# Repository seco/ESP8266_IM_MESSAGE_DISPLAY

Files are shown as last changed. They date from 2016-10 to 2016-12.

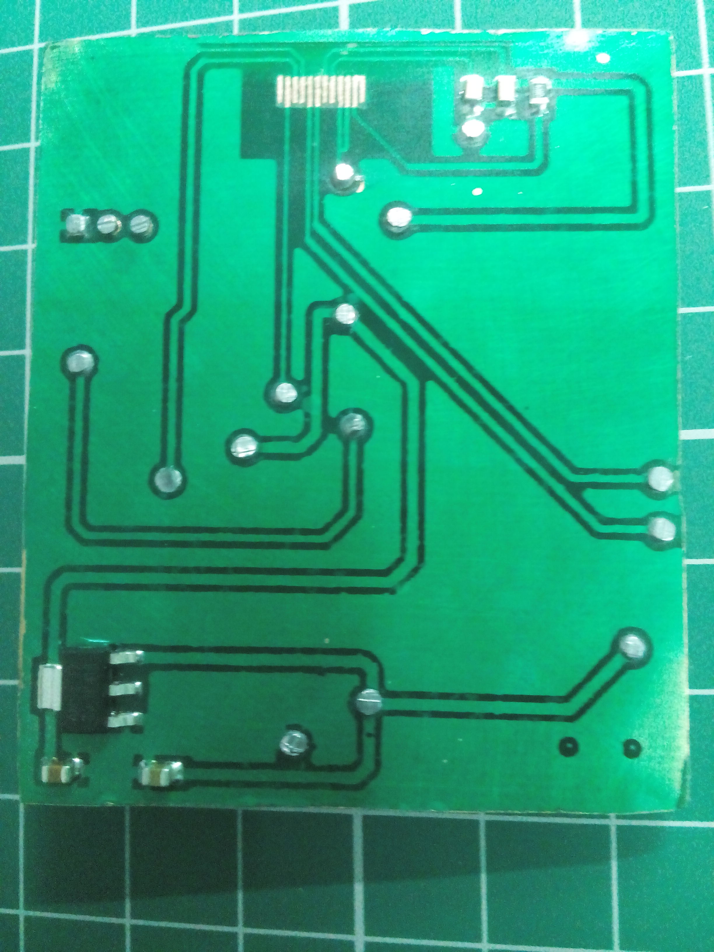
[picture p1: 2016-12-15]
pics/IMG_20161213_000737.jpg

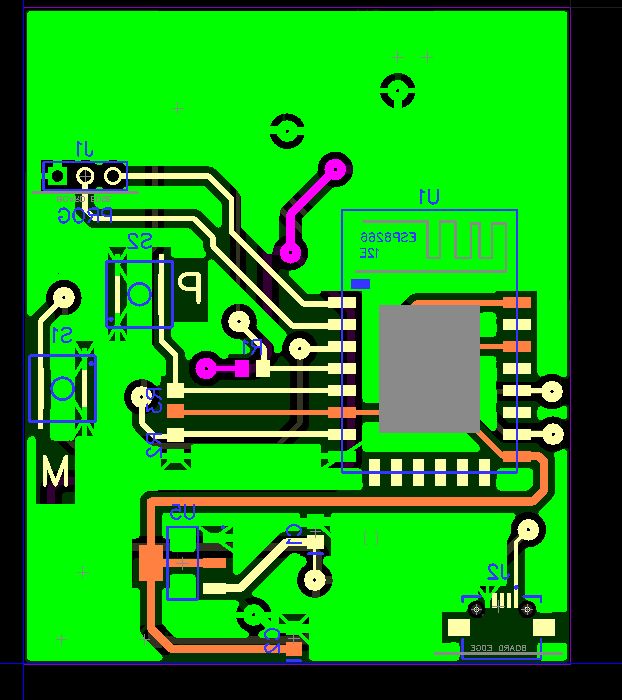
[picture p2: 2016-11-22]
pics/pcb1.jpg

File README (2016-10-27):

**************************************************************************************************
***********************************        README      *******************************************
**************************************************************************************************

1. The project has the main source code files in the 'user' folder

2. 'libs' subfolder within the user folder contains files for my custom libraries. These include
   stuff like specific IC libs, SPI libs etc. they are used as SUBMODULES from sourcetree

3. These libraries (within the libs folder) are PRIMARILY stored and maintained in a Github repository.
   In these main repos I do the code edits, feature addition etc. independent of the cloned copies.
   
4. To be used in a project, the main library set as a SUBMODULE in SOURCETREE in the 'user\libs' folder
   within the project folder
   
   NOTE : DO NOT PUSH ANY PROJECT SPECIFIC CHANGES FROM THESE CLONED REPOS BACK TO THE MAIN LIBRARY REPO.
          IF SOMETHING NEEDS TO BE CHANGED IN THE LIBRARY, DO IT IN THE MAIN REPO.
                    
          THIS STRUCTURE ALLOWS ME TO DO ANY PROJECT SPECIFIC CHANGES TO THE LIBRARY WITHOUT
          DISTUBING THE ORIGINAL LIBRARY
          
5. WITH THIS IN PLACE, IF I DO ANY CHANGES TO THE MAIN LIBRARY REPO, FOR THOSE CHANGES TO REFLECT INTO
   THE CLONED ONES, I HAVE TO DO FETCH + PULL IN THE SUBMODULE OF THE LIBRARY IN SOURCETREE
          
5. For this structure to compile, the following were added to Makefile
   
   MODULES	= driver user user/libs/ESP8266_SPI user/libs/MAX7221_7219 
   EXTRA_INCDIR = include $(SDK_BASE)/../extra/include
   EXTRA_INCDIR := $(EXTRA_INCDIR) C:/Espressif/ESP8266_SDK/driver_lib/include/driver
   
   UNDER MODULES VARIABLE OF MAKEFILE I NEED TO LIST THE COMPLETE RELATIVE PATH OF ALL THE SUBFOLDERS WHERE
   ANY OF MY CODE RESIDES.
   
   The last line modifying EXTRA_INCDIR variable lets me refer to code in driver_lib folder of the ESP SDK
   without copying the source/header files from there into my eclipse project folder.
   
-----------------------------------------------------------------------------------------------------------
Refer to https://blog.sourcetreeapp.com/2012/02/01/using-submodules-and-subrepositories/ for info on the
working of submodules
-----------------------------------------------------------------------------------------------------------

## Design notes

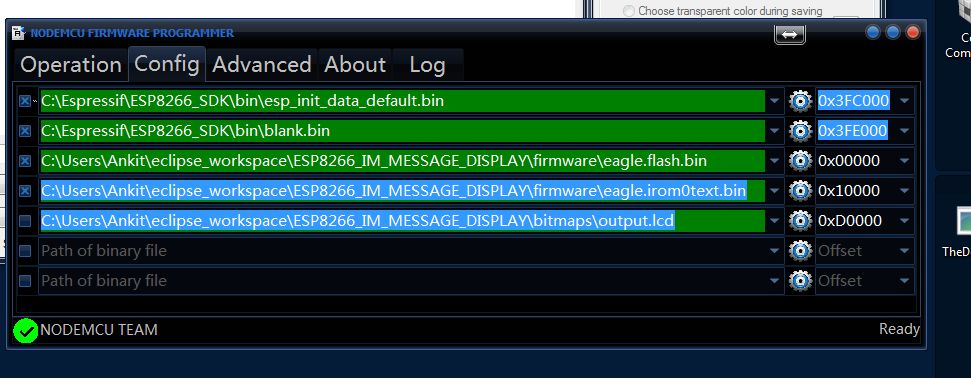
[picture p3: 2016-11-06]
pics/nodemcu_esp8266_4mb_flash_burn_setting_with_bitmap_in_flash.jpg

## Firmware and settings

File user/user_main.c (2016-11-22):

/*************************************************
* ESP8266 IM MESSAGE DISPLAY
*
* OCTOBER 21 2016
* ANKIT BHATNAGAR
* ANKIT.BHATNAGARINDIA@GMAIL.COM
* ***********************************************/

//////////////////////////////////
//INCLUDES
/////////////////////////////////
#include <osapi.h>
#include <ets_sys.h>			//NEEDS TO BE THERE IN EVERY ESP8266 PROGRAM
#include "user_interface.h"		//NEEDS TO BE THERE IN EVERY ESP8266 PROGRAM
#include "uart.h"
#include "smartconfig.h"
#include "LCD_NOKIA_C100.h"
#include "application.h"

//////////////////////////////////
//FUNCTION PROTOTYPES
//////////////////////////////////
void ICACHE_FLASH_ATTR esp8266_init_complete(void);
void ICACHE_FLASH_ATTR setup_gpio_pins(void);
void ICACHE_FLASH_ATTR wifi_event_handler_function(System_Event_t* event);
void ICACHE_FLASH_ATTR smartconfig_done_function(sc_status status, void* pdata);

//////////////////////////////////
//GLOBAL VARIABLES
//////////////////////////////////


void ICACHE_FLASH_ATTR user_init(void)
{
	//SET USART0 BAUD RATE TO 115200 BPS
	//BY DEFAULT PIN GPIO1 SET TO UART0 TXD FUNCTIONALITY
	uart_div_modify(0, UART_CLK_FREQ / 115200);

	//SET UP GPIO PONS
	setup_gpio_pins();

	//REGISTER CALLBACK FUNCTION FOR ENVIRONMENT INITIALIZATION DONE
	system_init_done_cb(esp8266_init_complete);
}

void ICACHE_FLASH_ATTR setup_gpio_pins(void)
{
	//INITIAL SETUP FOR GPIO PINSs
	//GPIO-D3 : OUTPUT : LED
	//GPIO-D5 : INPUT  : MODE SELECT PUSH BUTTON (NORMAL / SMARTCONFIG)
	//GPIO-D0  : INPUT  : CLEAR MESSAGE PUSH BUTTON

	WRITE_PERI_REG(PERIPHS_IO_MUX, 0x105);
	PIN_FUNC_SELECT(PERIPHS_IO_MUX_GPIO5_U, FUNC_GPIO5);
	PIN_PULLUP_EN(PERIPHS_IO_MUX_GPIO5_U);
	GPIO_DIS_OUTPUT(GPIO_ID_PIN(5));
	PIN_FUNC_SELECT(PERIPHS_IO_MUX_GPIO0_U, FUNC_GPIO0);

	//INITIALIZA SPI
	ESP8266_SPI_init_pins();

	//INITIALIZE NOKIA LCD RESET PIN
	LCD_NOKIA_C100_set_pins();
}

void ICACHE_FLASH_ATTR esp8266_init_complete(void)
{
	os_printf("ESP8266 module init complete\n");

	//INITIALIZE APPLICATION
	application_init();

	uint32_t id = spi_flash_get_id();
	os_printf("flash id %X\n", id);
	enum flash_size_map m = system_get_flash_size_map();
	switch(m)
	{
		case FLASH_SIZE_4M_MAP_256_256:
			os_printf("FLASH_SIZE_4Mbit_MAP_256_256\n");
			break;
		case FLASH_SIZE_2M:
			os_printf("FLASH_SIZE_2Mbit\n");
			break;
		case FLASH_SIZE_8M_MAP_512_512:
			os_printf("FLASH_SIZE_8Mbit_MAP_512_512\n");
			break;
		case FLASH_SIZE_16M_MAP_512_512:
			os_printf("FLASH_SIZE_16Mbit_MAP_512_512\n");
			break;
		case FLASH_SIZE_32M_MAP_512_512:
			os_printf("FLASH_SIZE_32Mbit_MAP_512_512\n");
			break;
		case FLASH_SIZE_16M_MAP_1024_1024:
			os_printf("FLASH_SIZE_16Mbit_MAP_1024_1024\n");
			break;
		case FLASH_SIZE_32M_MAP_1024_1024:
			os_printf("FLASH_SIZE_32Mbit_MAP_1024_1024\n");
			break;
	}

	//SPI CLK = 5Mhz (75% duty)
	ESP8266_SPI_set_params(1,8, 8, 2, 3, 0);

	//CLEAR LCD
	LCD_NOKIA_C100_init();
	LCD_NOKIA_C100_clear_screen(LCD_NOKIA_C100_COLOR_BLACK);

	//NEED TO INIT THE LCD AGAIN TO MAKE IT WORK AS ON
	//POWER ON ESP SAMPLES/DRIVES THE GPIO WHICH I AM NOT
	//SURE ABOUT. THIS CAUSES LCD TO NOT INIT PROPERLY.
	//TO MAKE IT WORK, NEED TO INIT AGAIN
	LCD_NOKIA_C100_init();
	LCD_NOKIA_C100_clear_screen(LCD_NOKIA_C100_COLOR_BLACK);

	//DRAW NOMADIC LOGO ON LCD
	application_draw_logo_bitmap();

	//PRINT SOME BASIC INFORMATION ABOUT THE MODULE ON DEBUG
	char system_mac[6];
	wifi_get_macaddr(STATION_IF, system_mac);
	os_printf("Module MAC ADDRESS : %02x:%02x:%02x:%02x:%02x:%02x\n", system_mac[0], system_mac[1], system_mac[2], system_mac[3], system_mac[4], system_mac[5]);

	//SET CUSTOM WIFI EVENT HANDLER FUNCTION
	wifi_set_event_handler_cb(wifi_event_handler_function);

	//DETERMINE WEATHER TO START IN STATION SMARTCONFIG MODE
	if(GPIO_INPUT_GET(5) == 0)
	{
		//MODE SELECTION BUTTON PRESSED
		//SMARTCONFIG MODE
		os_printf("smartconfig mode\n");

		//PRINT ON LCD
		application_draw_smartconfig_message();

		//START SMARTCONFIG
		//NEED THE MODULE TO BE IN STATION MODE FIRST FOR SMARTCONFIG TO WORK
		wifi_set_opmode(STATION_MODE);
		smartconfig_start(smartconfig_done_function, SC_TYPE_ESPTOUCH);
	}
	else
	{
		//NORMAL MODE
		os_printf("normal operation mode\n");
		//CONNECT TO WIFI NETWORK
		//USED INTERNALLY SAVED CONFIGURATION
		wifi_set_opmode(STATION_MODE);
		wifi_station_connect();
	}
}

void ICACHE_FLASH_ATTR wifi_event_handler_function(System_Event_t* event)
{
	//WIFI EVENT HANDLER FUNCTION
	//SIMPLY PRINTS THE NAME OF THE WIFI EVENT FOR DEBUGGING

	switch(event->event)
	{
		case EVENT_STAMODE_CONNECTED:
			os_printf("EVENT : EVENT_STAMODE_CONNECTED\n");
			break;

		case EVENT_STAMODE_DISCONNECTED:
			os_printf("EVENT : EVENT_STAMODE_DISCONNECTED\n");
			break;

		case EVENT_STAMODE_AUTHMODE_CHANGE:
			os_printf("EVENT : EVENT_STAMODE_AUTHMODE_CHANGE\n");
			break;

		case EVENT_STAMODE_GOT_IP:
			os_printf("EVENT : EVENT_STAMODE_GOT_IP\n");
			os_printf("*** COMPLETE INIT DONE ***\n");

			application_draw_ip_address();

			//ENABLE INTERRUPT ON PUSH BUTTON PIN (GPIO5)
			application_setup_push_button_interrupt();

			//CREATE UDP LISTENER FOR IM MESSAGES ON PORT 22837
			application_set_im_udp_listener(22837);

			uint8_t i = 0;
			for(i=0; i<21; i++)
			{
				os_delay_us(50000);
			}
			LCD_NOKIA_C100_clear_screen(LCD_NOKIA_C100_COLOR_BLACK);


			//GET THE TIME FROM NTP FOR THE FIRST TIME ON INTILIZATION
			application_get_time_ntp();

			//START THE TIME TICKER FUNCTIONS
			application_start_timer_tick();


			break;

		case EVENT_SOFTAPMODE_STACONNECTED:
			os_printf("EVENT : EVENT_SOFTAPMODE_STACONNECTED\n");
			break;

		case EVENT_SOFTAPMODE_STADISCONNECTED:
			os_printf("EVENT : EVENT_SOFTAPMODE_STADISCONNECTED\n");
			break;

		default:
			os_printf("Unknown EVENT %d\n", event->event);
	}
}


void ICACHE_FLASH_ATTR smartconfig_done_function(sc_status status, void* pdata)
{
	switch(status)
	{
		case SC_STATUS_WAIT:
			os_printf("SMARTCONFIG - SC_STATUS_WAIT\n");
			break;

		case SC_STATUS_FIND_CHANNEL:
			os_printf("SMARTCONFIG - SC_STATUS_FIND_CHANNEL\n");
			break;

		case SC_STATUS_GETTING_SSID_PSWD:
			os_printf("SMARTCONFIG - SC_STATUS_GETTING_SSID_PSWD\n");
			sc_type* type = pdata;
			if(*type == SC_TYPE_ESPTOUCH)
			{
				os_printf("SMARTCONFIG - SC_TYPE_ESPTOUCH\n");
			}
			else
			{
				os_printf("SMARTCONFIG - SC_TYPE_AIRKISS\n");
			}
			break;

		case SC_STATUS_LINK:
			os_printf("SMARTCONFIG - SC_STATUS_LINK\n");
			struct station_config *sta_conf = pdata;
			wifi_station_set_config(sta_conf);
			wifi_station_disconnect();
			wifi_station_connect();
			//SET AUTO CONNECT = ON
			wifi_station_set_auto_connect(1);
			break;

		case SC_STATUS_LINK_OVER:
			os_printf("SMARTCONFIG - SC_STATUS_LINK_OVER\n");
			if(pdata != NULL)
			{
				//ESP_TOUCH TYPE
				uint8_t phone_ip[4] = {0,0,0,0};
				os_memcpy(phone_ip, (uint8_t*)pdata, 4);
				os_printf("SMARTCONFIG - PHONE IP : %d.%d.%d.%d\n", phone_ip[0], phone_ip[1], phone_ip[2], phone_ip[3]);
			}
			else
			{
				//ESP_AIRKISS TYPE
				os_printf("SMARTCONFIG - THIS FIRMEARE DOES NOT SUPPORT AIRKISS\n");
			}
			smartconfig_stop();
			//SMARTCONFIG DONE
			os_printf("*** smartconfig done\n");
			break;
	}
}


//THIS FUNCTION IS REQUIRED TO BE IN USER_MAIN.C BY ESP8266 SDK
//COPIED FROM SDK EXAMPLES
uint32 ICACHE_FLASH_ATTR user_rf_cal_sector_set(void)
{
    enum flash_size_map size_map = system_get_flash_size_map();
    uint32 rf_cal_sec = 0;

    switch (size_map) {
        case FLASH_SIZE_4M_MAP_256_256:
            rf_cal_sec = 128 - 5;
            break;

        case FLASH_SIZE_8M_MAP_512_512:
            rf_cal_sec = 256 - 5;
            break;

        case FLASH_SIZE_16M_MAP_512_512:
        case FLASH_SIZE_16M_MAP_1024_1024:
            rf_cal_sec = 512 - 5;
            break;

        case FLASH_SIZE_32M_MAP_512_512:
        case FLASH_SIZE_32M_MAP_1024_1024:
            rf_cal_sec = 1024 - 5;
            break;

        default:
            rf_cal_sec = 0;
            break;
    }

    return rf_cal_sec;
}

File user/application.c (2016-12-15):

#include "application.h"

//////////////////////////////////
//GLOBAL VARIABLES
//////////////////////////////////
const char days_in_month[] = {
								31, //MARCH
								30, //APRIL
								31, //MAY
								30, //JUNE
								31, //JULY
								31, //AUGUST
								30, //SEPT
								31, //OCT
								30, //NOV
								31, //DEC
								31, //JAN
								29	//FEB
							};

const uint8_t* month_names[12] = {
									"March",
									"April",
									"May",
									"June",
									"July",
									"August",
									"September",
									"October",
									"November",
									"December",
									"January",
									"February"
								};

const uint8_t month_names_length[12] = {
										 5,	//MARCH
										 5,	//APRIL
										 3,	//MAY
										 4,	//JUNE
										 4, //JULY
										 6,	//AUG
										 9,	//SEPT
										 7,	//OCT
										 8,	//NOV
										 8,	//DEC
										 7,	//JAN
										 8	//FEB
									};

const uint8_t ntp_server_list[3][4] = {
										{128, 138, 140, 044},
										{216, 229, 000, 179},
										{066, 199, 022, 067}
									};

uint8_t ntp_current_server_index = 0;
uint8_t ntp_switch_ip_timer_started = 0;
os_timer_t ntp_server_timer;
uint8_t ntp_successfull = 0;

struct time* NTP_TIME;
struct message_box* IM_MESSAGE_BOX;
os_timer_t timer_tick_timer;
uint32_t timer_tick_count;
uint8_t second_dash_x_count;
struct ESP8266_UDP_HANDLE* ntp_handle;

void ICACHE_FLASH_ATTR application_init(void)
{
	//INITIALIZE APPLICATION VARIABLES
	NTP_TIME = (struct time*)os_zalloc(sizeof(struct time));
	IM_MESSAGE_BOX = (struct message_box*)os_zalloc(sizeof(struct message_box));
	timer_tick_count = 0;
	second_dash_x_count = 1;
	ntp_handle = NULL;
}

void ICACHE_FLASH_ATTR application_set_im_udp_listener(uint16_t port)
{
	//SETUP THE UDP LISTENER FOR THE IM BOX MESSAGES

	struct ESP8266_UDP_HANDLE *h = (struct ESP8266_UDP_HANDLE*)os_zalloc(sizeof(struct ESP8266_UDP_HANDLE));
	ESP8266_UDP_create_listener(port, &application_im_udp_listener_cb, h);
	os_printf("created udp listener on port %d\n", port);
}

void ICACHE_FLASH_ATTR application_im_udp_listener_cb(void* arg, char* pdata, uint16_t len)
{
	//CALLBACK FUNCTION FOR UDP IM MESSAGES
	//BYTE 0 : NAME (LETTER TO PRINT INSIDE BOX)
	//BYTE 1 : LOCATION OF BOX (0-3)

	os_printf("received im message of len %d\n", len);
	os_printf("drawing box at location %d with letter %c\n", pdata[1], pdata[0]);
	application_draw_im_notification_box(pdata[1], pdata[0]);
}

void ICACHE_FLASH_ATTR application_setup_push_button_interrupt(void)
{
	//SETUP THE PUSH BUTTON INTERRUPT FOR BUTTON
	//CONNECTED TO GPIO 5

	//ENABLE INTERRUPT ON PUSH BUTTON PIN (GPIO5)
	//INTERRUPT ON LOW TO HIGH
	ETS_GPIO_INTR_DISABLE();
	ETS_GPIO_INTR_ATTACH(application_push_button_interrupt_cb, 5);
	gpio_pin_intr_state_set(GPIO_ID_PIN(5), GPIO_PIN_INTR_NEGEDGE);
	ETS_GPIO_INTR_ENABLE();
}

void ICACHE_FLASH_ATTR application_push_button_interrupt_cb(void* arg)
{
	//PUSH BUTTON INTERRUPT ISR

	uint32 status = GPIO_REG_READ(GPIO_STATUS_ADDRESS);
	if(status & BIT(5))
	{
		os_printf("push btn interrupt\n");
		application_clear_im_notification_box();

		// Clear interrupt
		 GPIO_REG_WRITE(GPIO_STATUS_W1TC_ADDRESS, status & BIT(5));
	}
}

void ICACHE_FLASH_ATTR application_send_ntp_request()
{
	//SEND A NTP TIME REQUEST PACKET TO NTP SERVER PORT 123 FROM LOCAL PORT 55555
	//AND GET THE REPLY

	ntp_successfull = 0;

	//setup ntp server switch timer
	//1 second ntp server switch
	if(ntp_switch_ip_timer_started == 0)
	{
		os_timer_setfn(&ntp_server_timer, application_switch_ntp_server_cb, NULL);
	}

	uint8_t packet[48] = {0};
	packet[0] = 0x0B;

	//CREATE NEW NTP UDP HANDLE IF NOT DONE YET
	if(ntp_handle == NULL)
	{
		ntp_handle = (struct ESP8266_UDP_HANDLE*)os_zalloc(sizeof(struct ESP8266_UDP_HANDLE));

	}
	os_printf("********\n");
	ESP8266_UDP_send_receive_data_ip(ntp_server_list[ntp_current_server_index][0], ntp_server_list[ntp_current_server_index][1],
									ntp_server_list[ntp_current_server_index][2], ntp_server_list[ntp_current_server_index][3],
									123 , 55555, packet, 48, application_ntp_udp_listener_cb, ntp_handle);

	os_printf("ntp request sent to ntp server %d. waiting for reply\n", ntp_current_server_index);

	//start ntp server switch timer, only if not already started
	if(ntp_switch_ip_timer_started == 0)
	{
		os_timer_arm(&ntp_server_timer, 1000, 1);
		ntp_switch_ip_timer_started = 1;
	}
}

void ICACHE_FLASH_ATTR application_switch_ntp_server_cb(void)
{
	//ntp server reply timed out.
	//switch the global ntp server list index variable
	//so that the next ntp server can be tried

	if(ntp_switch_ip_timer_started == 1)
	{
		ntp_current_server_index++;
		os_printf("switching ntp server index to %d\n", ntp_current_server_index);

		if(ntp_current_server_index == 3)
		{
			//all 3 ntp servers have been tried
			//and exhausted
			os_printf("all ntp servers tried and exhausted. no reply !\n");
			LCD_NOKIA_C100_draw_text(10, 15, courierNew_10ptBitmaps, courierNew_10ptDescriptors, 2, 13, "NTP Error" , 9, LCD_NOKIA_C100_COLOR_RED, LCD_NOKIA_C100_COLOR_BLACK);

			ntp_switch_ip_timer_started = 0;
			ntp_current_server_index = 0;

			//disable and turn off timer
			os_timer_disarm(ntp_server_timer);

			ntp_successfull = 0;
		}
		else
		{
			//send a new ntp request with the new server
			application_send_ntp_request();
		}
	}
}

void ICACHE_FLASH_ATTR application_ntp_udp_listener_cb(void* arg, char* pdata, uint16_t len)
{
	//CALLBACK FUNCTION FOR NTP REPLY

	//received reply from ntp server
	//stop the ntp server switch timer
	//ntp successfull
	os_timer_disarm(&ntp_server_timer);
	ntp_switch_ip_timer_started = 0;
	ntp_current_server_index = 0;
	ntp_successfull = 1;

	os_printf("received NTP message of len %d\n", len);
	//extract the 32 bit timestamp from ntp reply
	uint32_t a = pdata[40];
	uint32_t b = pdata[41];
	uint32_t c = pdata[42];
	uint32_t d = pdata[43];

	NTP_TIME->time_tick = (a << 24) | (b << 16) | (c << 8) | d;

	os_printf("ntp timestamp %d\n", NTP_TIME->time_tick);

	//reset timer tick count
	timer_tick_count = 0;

	//populate time parameters from the timestamp
	application_get_time_components_from_ntp_timestamp();

	application_print_time();
}

void ICACHE_FLASH_ATTR application_get_time_ntp(void)
{
	//GET THE TIME FROM NTP SERVER
	//SEND NTP REQUEST AND CREATE A LISTENER FOR REPLY

	ntp_successfull = 0;
	ntp_switch_ip_timer_started = 0;
	ntp_current_server_index = 0;

	application_send_ntp_request();
}
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

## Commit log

2016-10-25 added code for led timer and smartconfig timer
2016-10-26 1. Added links to MAX7221 and ESP8266 SPI libraries 2. changed comments to upper case 3. Changed code so that smartconfig mode / normal mode is determined by the value of a push button at power on
2016-10-26 Fixed eclipse linking (removed driver lib from the source code folder) and made changes to makefile to link to my own libraries. Added skeleton for ESP8266_SPI and MAX7221 libraries
    [user_main.c]
2016-10-26 fixed the project Makefile to be able to include custom code folders outside of eclipse project user code folder.
    [user_main.c]
2016-11-02 added FLASH submodule and a dirty workaround to reset the unit once after every powerup or smartconfig (using value stored in flash) as thats the only way NOKIA lcd would work
    [user_main.c]
2016-11-06 added application code files + added push button interrupt
2016-11-07 removed led code + added pcb files
2016-11-13 added final application code + pictures + updated pcb
2016-11-22 added code to cycle through 3 preconfigured ntp servers for time and display error if none working + updated pcb / schematic to include microusb power source and smd push buttons
    [BoardOutline.gbr, BottomMask.gbr, TopMask.gbr]
